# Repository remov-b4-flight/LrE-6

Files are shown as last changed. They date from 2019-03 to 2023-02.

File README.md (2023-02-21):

Current development was moved to 8-Axis [LrTMAX](https://github.com/remov-b4-flight/LrTMAX) repository.
***
# LrE-6
Adobe Lightroom MIDI Developer Controller project (STM32F072Cx based)  
LrE-6 MIDI controller is formed by embedded hardware board and its firmware.  
It used with [MIDI2LR](https://github.com/rsjaffe/MIDI2LR) software,  
You can control development parameters on RAW photos.  
[YouTube](https://www.youtube.com/watch?v=oeDpP1sG9_Y)  
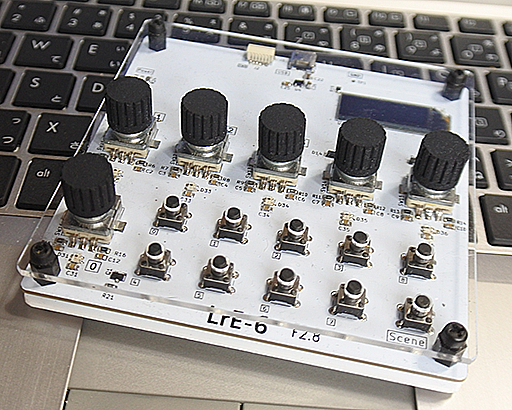
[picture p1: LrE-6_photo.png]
  
Information related Build,Configure & Use are exists on wiki.  
***
Lightroom is Registerd Trademark of Adobe Corp.

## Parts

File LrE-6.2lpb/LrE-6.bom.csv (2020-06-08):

Reference | Quantity | Value | Footprint | Datasheet
C1 C2 C3 C4 C7 C8 C9 C10 C11 C12 C5 C6 C25 | 13 | 0.01u | Capacitor_SMD:C_0805_2012Metric | ~
C13 C16 C17 C18 C14 | 5 | 0.1u | Capacitor_SMD:C_0603_1608Metric | ~
C15 C19 C28 C29 | 4 | 4.7u | Capacitor_SMD:C_0805_2012Metric | ~
C26 C22 C23 C24 C21 C20 C27 | 7 | 1u | Capacitor_SMD:C_0805_2012Metric | ~
C31 C32 C33 C35 C36 C34 C30 | 7 | 0.1u | Capacitor_SMD:C_0805_2012Metric | ~
D18 | 1 | LED0603_BL | LED_SMD:LED_0603_1608Metric | ~
D31 D32 D33 D34 D35 D36 | 6 | WS2812B-2020 | LrE-6:LED_WS2812B-2020 | https://cdn-shop.adafruit.com/product-files/2686/SK6812MINI_REV.01-1-2.pdf
D4 D9 D3 D8 D2 D7 D10 D1 D6 D5 D12 D11 D13 D14 D15 D16 | 16 | 1N4148W | LrE-6:D_SOD-123 | https://www.vishay.com/docs/85748/1n4148w.pdf
H1 H2 H3 H4 | 4 | MountingHole | MountingHole:MountingHole_3.2mm_M3 | ~
J1 | 1 | USB_B_Micro | LrE-6:USB_Micro-B_MCUBF-09_1 | ~
J2 | 1 | SM06B-SRSS-TB | Connector_JST:JST_SH_SM06B-SRSS-TB_1x06-1MP_P1.00mm_Horizontal | ~
Q1 | 1 | 2N7002 | Package_TO_SOT_SMD:SOT-23 | https://www.fairchildsemi.com/datasheets/2N/2N7002.pdf
R18 | 1 | 62 | Resistor_SMD:R_0805_2012Metric | ~
R19 R20 R6 R5 R8 R7 R10 R9 R12 R11 R14 R13 R16 R15 R17 R21 | 16 | 10K | Resistor_SMD:R_0805_2012Metric | ~
R23 | 1 | 100 | Resistor_SMD:R_0805_2012Metric | ~
R4 R3 R2 R1 R24 R22 | 6 | 1K | Resistor_SMD:R_0805_2012Metric | ~
SW1 SW2 SW3 SW4 SW5 SW6 SW7 SW8 SW9 SW10 | 10 | Tact_SW_8mm | Button_Switch_THT:SW_PUSH_6mm_H9.5mm
SW11 SW12 SW13 SW14 SW15 SW16 | 6 | EC11_SMD | LrE-6:RotaryEncoder_EC11E-SMD2 | ~
TP1 | 1 | TestPoint | TestPoint:TestPoint_THTPad_D1.0mm_Drill0.5mm | ~
U1 | 1 | STM32F072C8Tx | Package_QFP:LQFP-48_7x7mm_P0.5mm | http://www.st.com/st-web-ui/static/active/en/resource/technical/document/datasheet/DM00090510.pdf
U3 | 1 | SSD1306_OLED_0.91 | LrE-6:OLED-9.1
U4 | 1 | SPX3819M5-L3-3TR | Package_TO_SOT_SMD:SOT-23-5 | http://www.st.com/content/ccc/resource/technical/document/datasheet/29/10/f7/87/2f/66/47/f4/DM00076097.pdf/files/DM00076097.pdf/jcr:content/translations/en.DM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

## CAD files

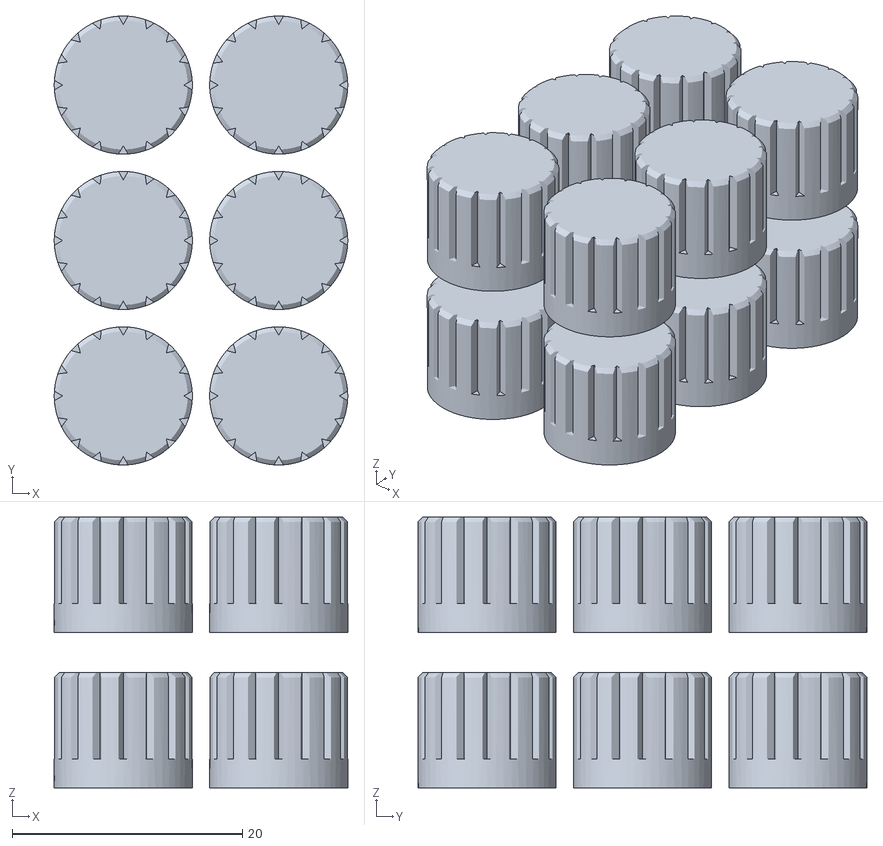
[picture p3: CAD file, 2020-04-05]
LrE-6.knob/knob12-hollow.stl
25.5 x 39.0 x 23.5

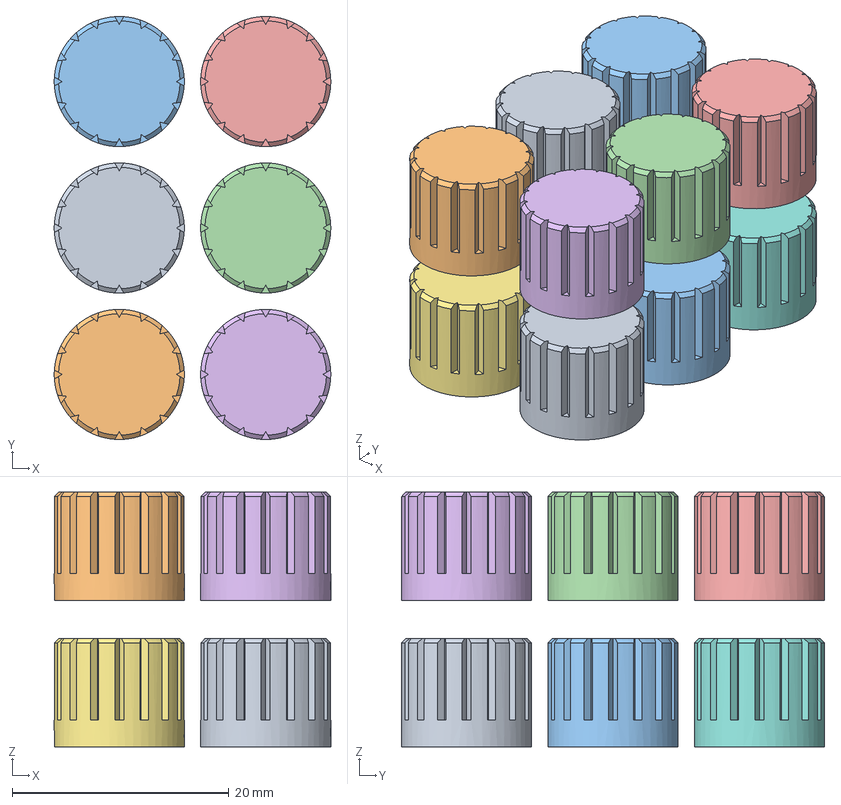
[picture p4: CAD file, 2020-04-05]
LrE-6.knob/KNOB12.FCStd
25.5 x 39.0 x 23.5 mm

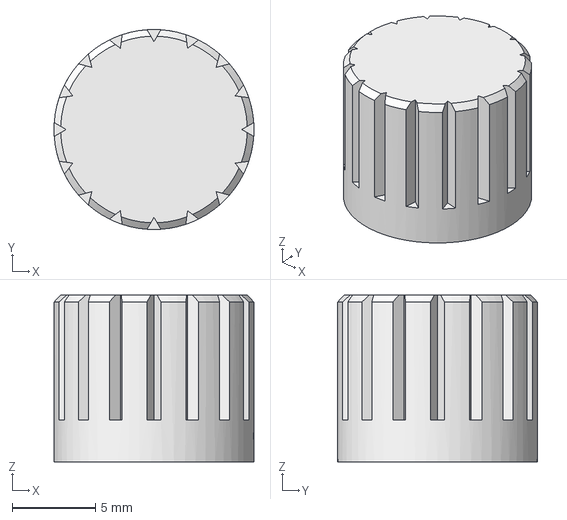
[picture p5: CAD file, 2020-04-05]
LrE-6.knob/KNOB1.FCStd
12.0 x 12.0 x 10.0 mm

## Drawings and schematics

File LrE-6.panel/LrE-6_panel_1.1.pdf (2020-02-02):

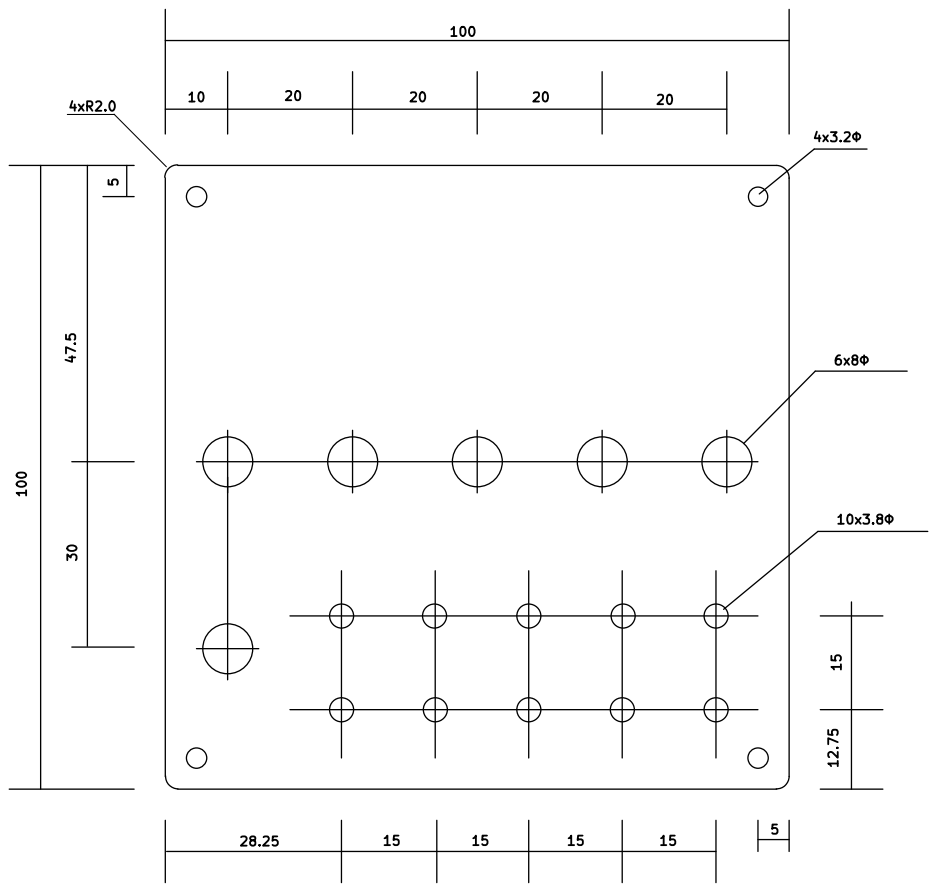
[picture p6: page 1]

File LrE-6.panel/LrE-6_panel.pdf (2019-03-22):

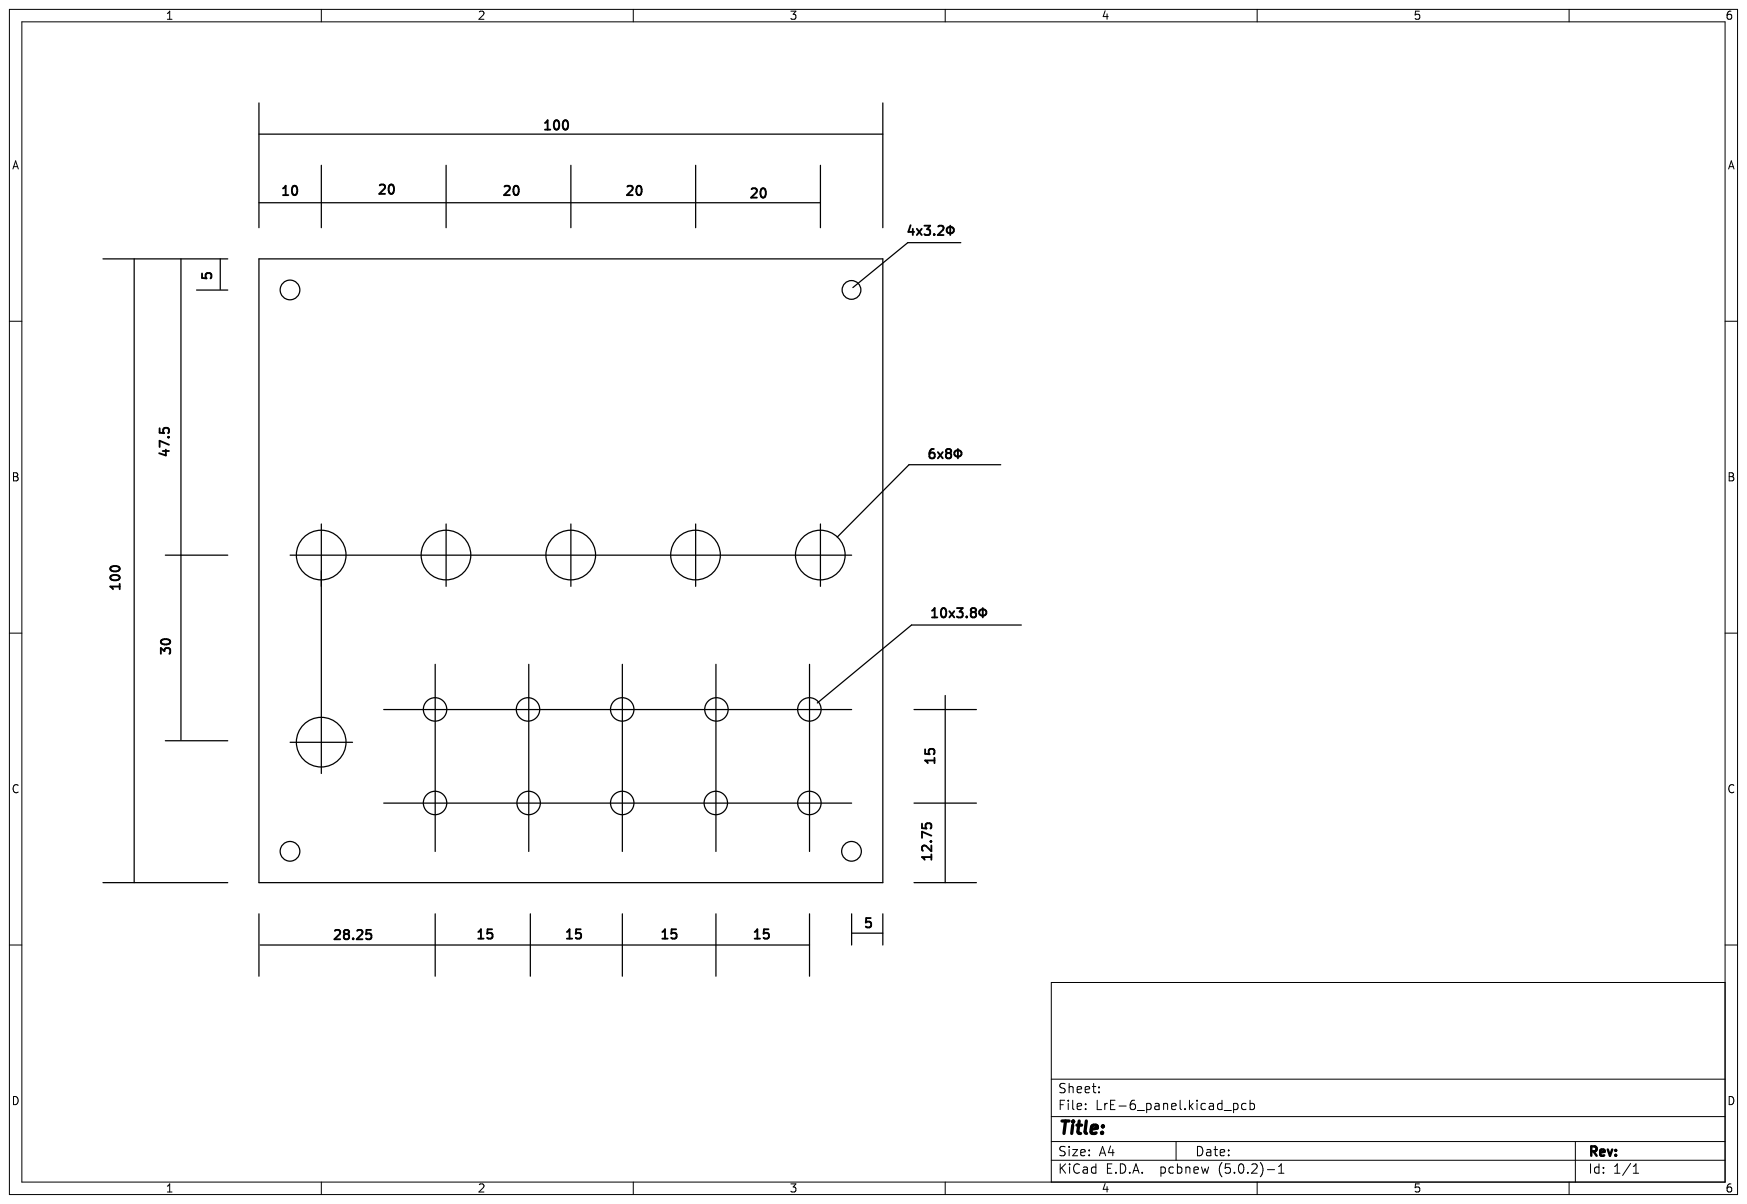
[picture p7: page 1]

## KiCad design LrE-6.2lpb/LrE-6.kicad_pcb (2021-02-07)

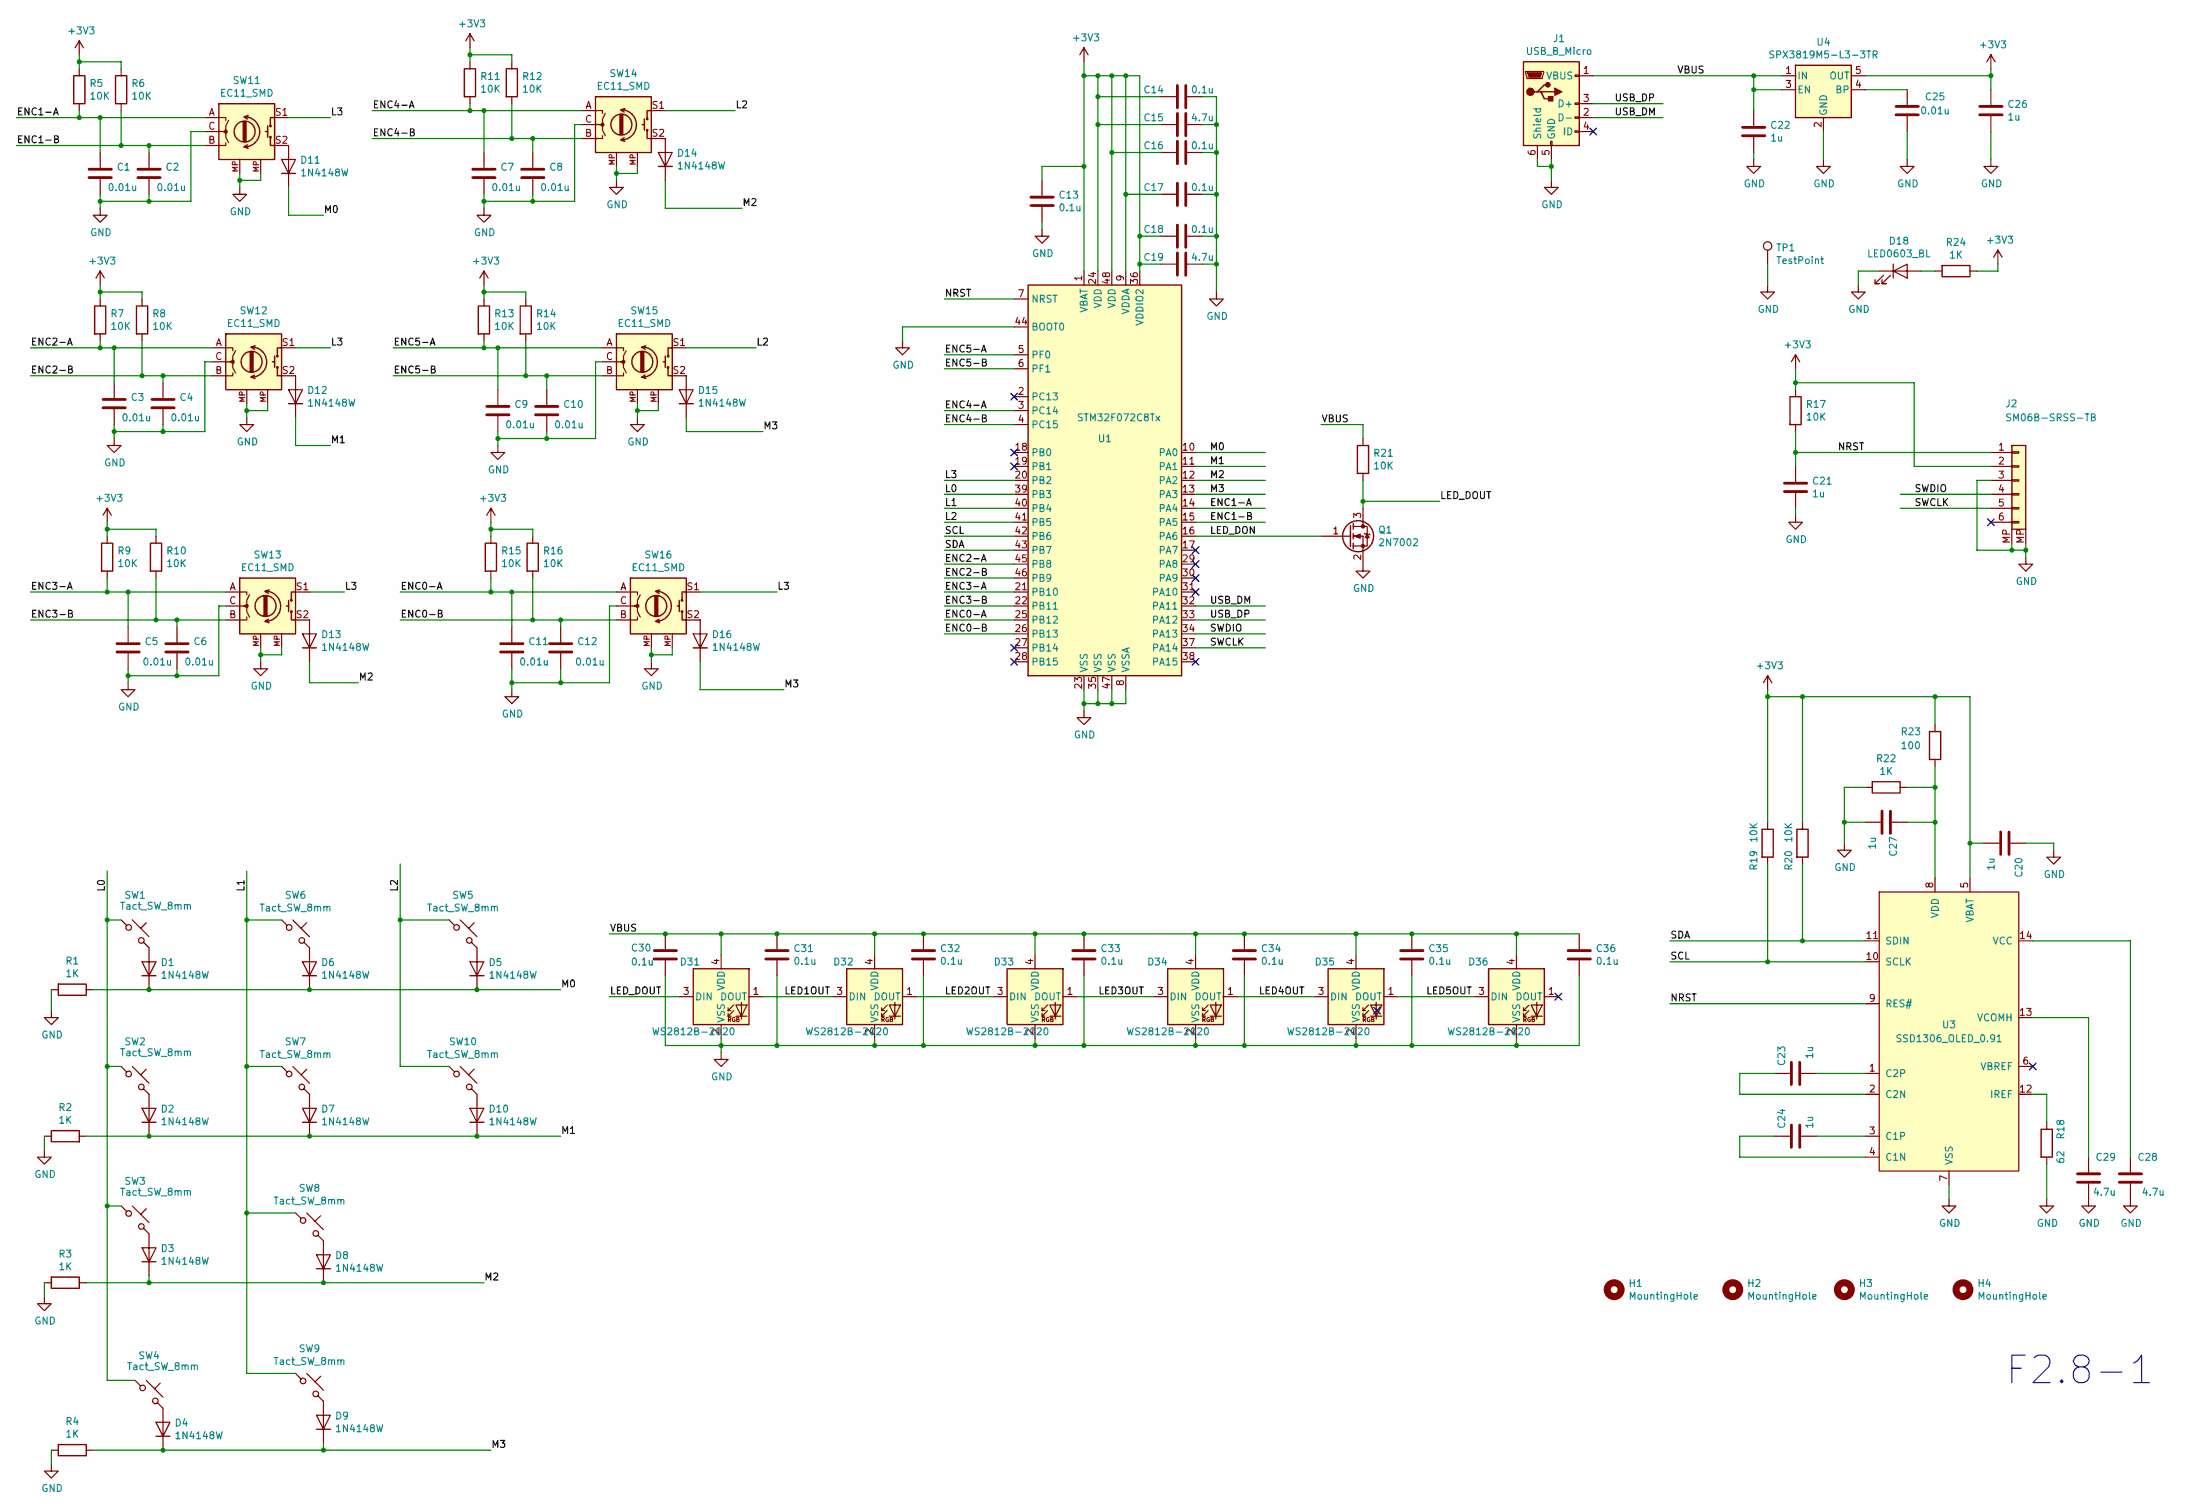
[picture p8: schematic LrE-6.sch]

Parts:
C1, C2, C3, C4, C5, C6, C7, C8, C9, C10, C11, C12, C25: 0.01u; C_0805_2012Metric
C13, C14, C16, C17, C18: 0.1u; C_0603_1608Metric
C15, C19, C28, C29: 4.7u; C_0805_2012Metric
C20, C21, C22, C23, C24, C26, C27: 1u; C_0805_2012Metric
C30, C31, C32, C33, C34, C35, C36: 0.1u; C_0805_2012Metric
D1, D2, D3, D4, D5, D6, D7, D8, D9, D10, D11, D12, D13, D14, D15, D16: 1N4148W; D_SOD-123
D18: LED0603_BL; LED_0603_1608Metric
D31, D32, D33, D34, D35, D36: WS2812B-2020; LED_WS2812B-2020
H1, H2, H3, H4: MountingHole; MountingHole_3.2mm_M3
J1: USB_B_Micro; USB_Micro-B_MCUBF-09_1
J2: SM06B-SRSS-TB; JST_SH_SM06B-SRSS-TB_1x06-1MP_P1.00mm_Horizontal
Q1: 2N7002; SOT-23
R1, R2, R3, R4, R22, R24: 1K; R_0805_2012Metric
R5, R6, R7, R8, R9, R10, R11, R12, R13, R14, R15, R16, R17, R19, R20, R21: 10K; R_0805_2012Metric
R18: 62; R_0805_2012Metric
R23: 100; R_0805_2012Metric
SW1, SW2, SW3, SW4, SW5, SW6, SW7, SW8, SW9, SW10: Tact_SW_8mm; SW_PUSH_6mm_H9.5mm
SW11, SW12, SW13, SW14, SW15, SW16: EC11_SMD; RotaryEncoder_Alps_EC11E-Switch_Vertical_H20mm
TP1: TestPoint; TestPoint_THTPad_D1.0mm_Drill0.5mm
U1: STM32F072C8Tx; LQFP-48_7x7mm_P0.5mm
U3: SSD1306_OLED_0.91; OLED-9.1
U4: SPX3819M5-L3-3TR; SOT-23-5

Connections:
+3V3: C13.1, C14.2, C15.2, C16.2, C17.2, C18.2, C19.2, C20.1, C26.1, J2.2, R5.1, R6.1, R7.1, R8.1, R9.1, R10.1, R11.1, R12.1, R13.1, R14.1, R15.1, R16.1, R17.1, R19.1, R20.1, R23.1, R24.1, U1.1 (VBAT), U1.9 (VDDA), U1.24 (VDD), U1.36 (VDDIO2), U1.48 (VDD), U3.5 (VBAT), U4.5 (OUT)
/ENC0-A: C11.1, R15.2, SW16.A, U1.25 (PB12)
/ENC0-B: C12.1, R16.2, SW16.B, U1.26 (PB13)
/ENC1-A: C1.1, R5.2, SW11.A, U1.14 (PA4)
/ENC1-B: C2.1, R6.2, SW11.B, U1.15 (PA5)
/ENC2-A: C3.1, R7.2, SW12.A, U1.45 (PB8)
/ENC2-B: C4.1, R8.2, SW12.B, U1.46 (PB9)
/ENC3-A: C5.1, R9.2, SW13.A, U1.21 (PB10)
/ENC3-B: C6.1, R10.2, SW13.B, U1.22 (PB11)
/ENC4-A: C7.1, R11.2, SW14.A, U1.3 (PC14)
/ENC4-B: C8.1, R12.2, SW14.B, U1.4 (PC15)
/ENC5-A: C9.1, R13.2, SW15.A, U1.5 (PF0)
/ENC5-B: C10.1, R14.2, SW15.B, U1.6 (PF1)
/L0: SW1.1, SW2.1, SW3.1, SW4.1, U1.39 (PB3)
/L1: SW6.1, SW7.1, SW8.1, SW9.1, U1.40 (PB4)
/L2: SW5.1, SW10.1, SW14.S1, SW15.S1, U1.41 (PB5)
/L3: SW11.S1, SW12.S1, SW13.S1, SW16.S1, U1.20 (PB2)
/LED1OUT: D31.1 (DOUT), D32.3 (DIN)
/LED2OUT: D32.1 (DOUT), D33.3 (DIN)
/LED3OUT: D33.1 (DOUT), D34.3 (DIN)
/LED4OUT: D34.1 (DOUT), D35.3 (DIN)
/LED5OUT: D35.1 (DOUT), D36.3 (DIN)
/LED_DON: Q1.1 (G), U1.16 (PA6)
/LED_DOUT: D31.3 (DIN), Q1.3 (D), R21.2
/M0: D1.1 (K), D5.1 (K), D6.1 (K), D11.1 (K), R1.1, U1.10 (PA0)
/M1: D2.1 (K), D7.1 (K), D10.1 (K), D12.1 (K), R2.2, U1.11 (PA1)
/M2: D3.1 (K), D8.1 (K), D13.1 (K), D14.1 (K), R3.1, U1.12 (PA2)
/M3: D4.1 (K), D9.1 (K), D15.1 (K), D16.1 (K), R4.1, U1.13 (PA3)
/NRST: C21.1, J2.1, R17.2, U1.7 (NRST), U3.9 (RES#)
/SCL: R19.2, U1.42 (PB6), U3.10 (SCLK)
/SDA: R20.2, U1.43 (PB7), U3.11 (SDIN)
/SWCLK: J2.5, U1.37 (PA14)
/SWDIO: J2.4, U1.34 (PA13)
/USB_DM: J1.2 (D-), U1.32 (PA11)
/USB_DP: J1.3 (D+), U1.33 (PA12)
/VBUS: C22.1, C30.1, C31.1, C32.1, C33.1, C34.1, C35.1, C36.1, D31.4 (VDD), D32.4 (VDD), D33.4 (VDD), D34.4 (VDD), D35.4 (VDD), D36.4 (VDD), J1.1 (VBUS), R21.1, U4.1 (IN), U4.3 (EN)
GND: C1.2, C2.2, C3.2, C4.2, C5.2, C6.2, C7.2, C8.2, C9.2, C10.2, C11.2, C12.2, C13.2, C14.1, C15.1, C16.1, C17.1, C18.1, C19.1, C20.2, C21.2, C22.2, C25.2, C26.2, C27.1, C28.1, C29.1, C30.2, C31.2, C32.2, C33.2, C34.2, C35.2, C36.2, D18.1 (K), D31.2 (VSS), D32.2 (VSS), D33.2 (VSS), D34.2 (VSS), D35.2 (VSS), D36.2 (VSS), J1.5 (GND), J1.6 (Shield), J2.3, J2.MP (GND), Q1.2 (S), R1.2, R2.1, R3.2, R4.2, R18.2, R22.2, SW11.C, SW11.MP (GND), SW12.C, SW12.MP (GND), SW13.C, SW13.MP (GND), SW14.C, SW14.MP (GND), SW15.C, SW15.MP (GND), SW16.C, SW16.MP (GND), TP1.1, U1.8 (VSSA), U1.23 (VSS), U1.35 (VSS), U1.44 (BOOT0), U1.47 (VSS), U3.7 (VSS), U4.2 (GND)
unnamed: C23.1, U3.2 (C2N)
unnamed: C23.2, U3.1 (C2P)
unnamed: C24.1, U3.4 (C1N)
unnamed: C24.2, U3.3 (C1P)
unnamed: C25.1, U4.4 (BP)
unnamed: C27.2, R22.1, R23.2, U3.8 (VDD)
unnamed: C28.2, U3.14 (VCC)
unnamed: C29.2, U3.13 (VCOMH)
unnamed: D1.2 (A), SW1.2
unnamed: D2.2 (A), SW2.2
unnamed: D3.2 (A), SW3.2
unnamed: D4.2 (A), SW4.2
unnamed: D5.2 (A), SW5.2
unnamed: D6.2 (A), SW6.2
unnamed: D7.2 (A), SW7.2
unnamed: D8.2 (A), SW8.2
unnamed: D9.2 (A), SW9.2
unnamed: D10.2 (A), SW10.2
unnamed: D11.2 (A), SW11.S2
unnamed: D12.2 (A), SW12.S2
unnamed: D13.2 (A), SW13.S2
unnamed: D14.2 (A), SW14.S2
unnamed: D15.2 (A), SW15.S2
unnamed: D16.2 (A), SW16.S2
unnamed: D18.2 (A), R24.2
unnamed: R18.1, U3.12 (IREF)

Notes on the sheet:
F2.8-1

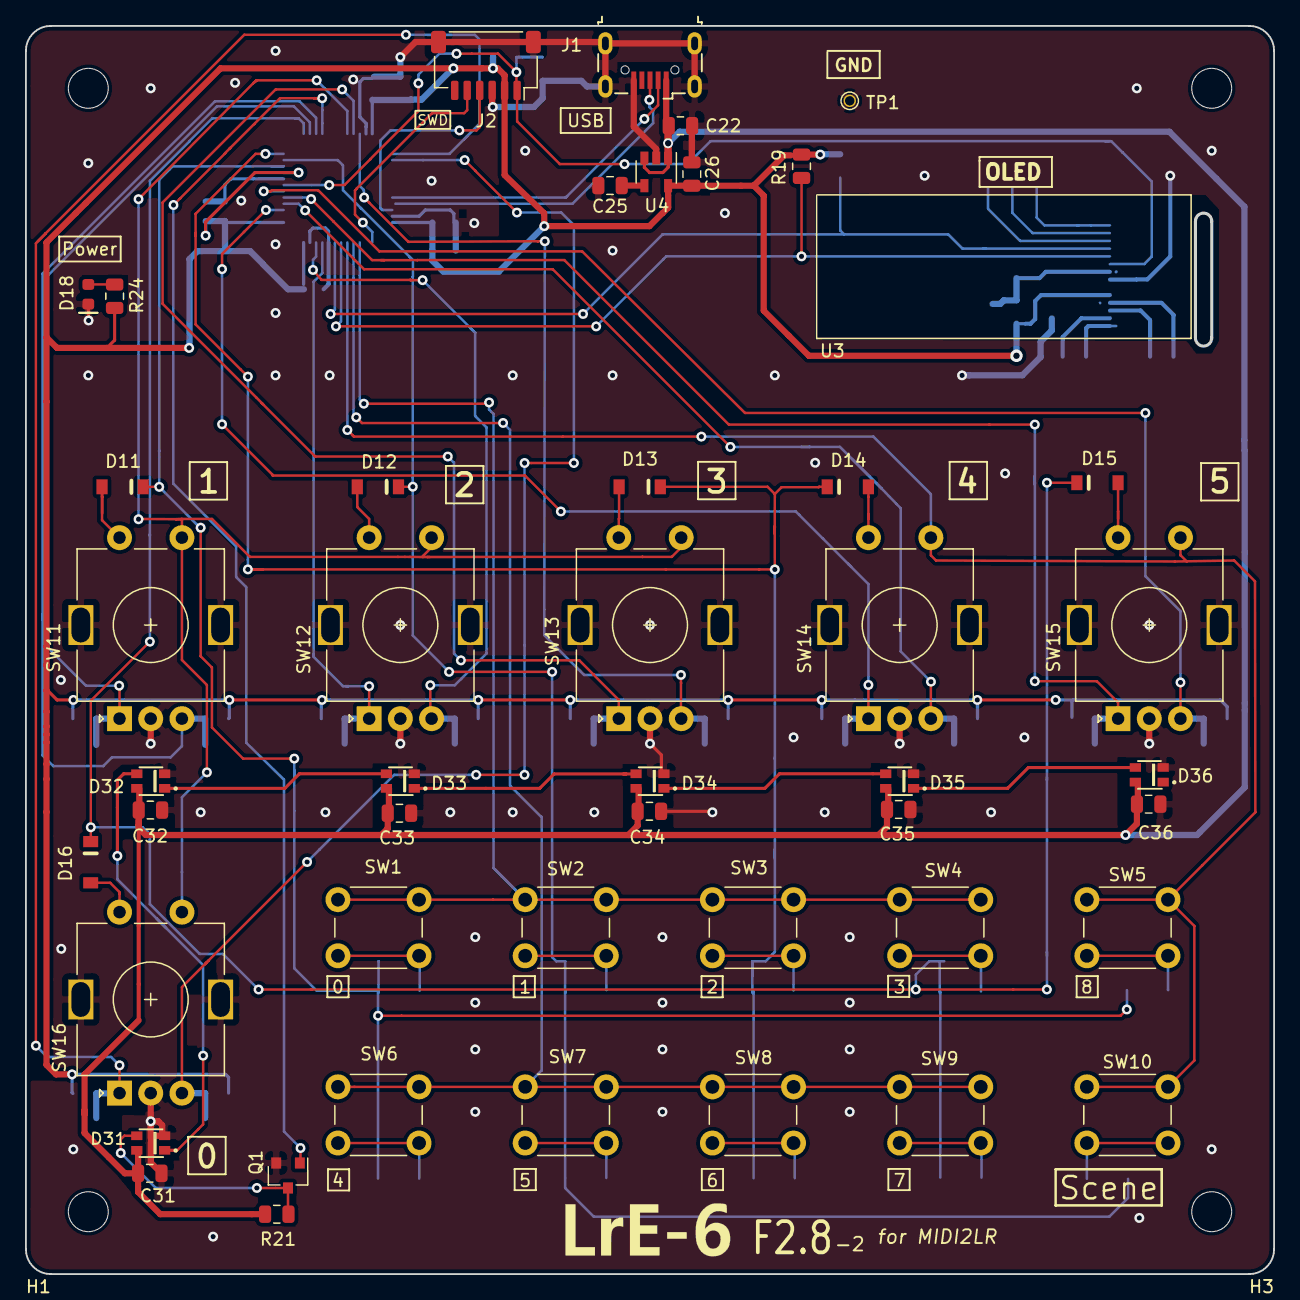
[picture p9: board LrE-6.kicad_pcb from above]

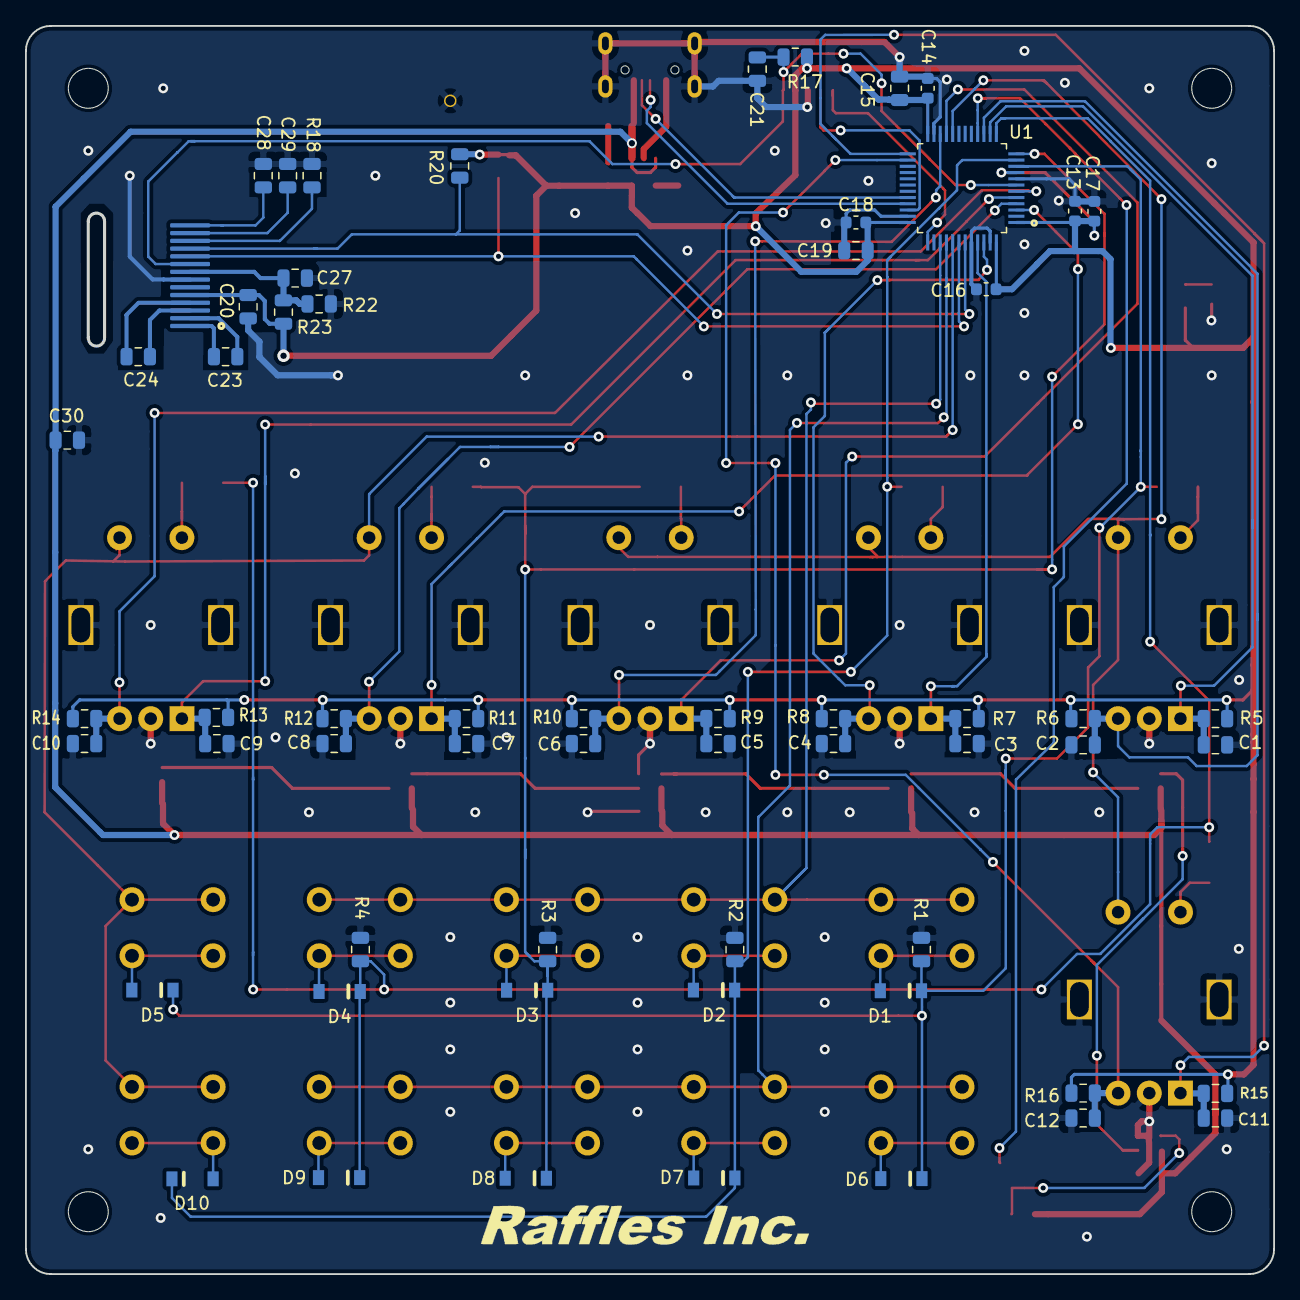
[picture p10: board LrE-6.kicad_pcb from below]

Board: 2 copper layers, 100.0 x 100.0 mm, 112 parts (60 on the bottom side), 63 nets.

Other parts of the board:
G001: LrE-6; LOGO
G002: LOGO; Raffles_Inc

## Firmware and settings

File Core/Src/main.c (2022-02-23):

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
/* Includes ------------------------------------------------------------------*/
#include "main.h"
#include "usb_device.h"

/* USER CODE BEGIN Includes */
#include <stdbool.h>
#include "midi.h"
#include "led.h"
#include "bitcount.h"
#include "key_define.h"
#include "usbd_midi_if.h"
#include "ssd1306.h"
/* USER CODE END Includes */

/* USER CODE BEGIN PTD */
#ifdef DEBUG
#define CONN_MSG_D	"%s %2x.%02xD"
#else
#define CONN_MSG	"%s %2x.%02x"
#endif
/* USER CODE END PTD */

I2C_HandleTypeDef hi2c1;
DMA_HandleTypeDef hdma_i2c1_tx;

TIM_HandleTypeDef htim1;
TIM_HandleTypeDef htim3;
TIM_HandleTypeDef htim6;
TIM_HandleTypeDef htim7;
TIM_HandleTypeDef htim14;
DMA_HandleTypeDef hdma_tim3_ch1_trig;

/* USER CODE BEGIN PV */

//! STM32 TIM3 instance handle
TIM_HandleTypeDef htim3;
extern	USBD_HandleTypeDef hUsbDeviceFS;
//! Lr**** USB connection state
uint8_t		LrState;
//! Lr**** Scene index
uint8_t		LrScene;
// keyboard variable
//! If true, ISR detected any Key/Encoder was moved.
bool		isKeyPressed;
//! Key pressed/released status set by timer key scanning.
KEYSCAN     Key_Stat;
//! In key scanning whether Line selected to read for key matrix.
uint8_t		Key_Line;
//! If true, MIDI event previous sent is switch. if false, it's encoder
bool		isPrev_sw;
//! Bit masks for which bit of KEYSCAN variable acts as key.
uint32_t	MaskKey[SCENE_COUNT];
//! Bit masks for which bit of KEYSCAN variable acts as encoder.
uint32_t	MaskEnc[SCENE_COUNT];

// OLED variables
//! Flag set by timer ISR, It makes 'off' OLES contents.
bool 		Msg_Timer_Update;
//! Timer counter ticked by end of L3 matrix scanning. (16ms interval).
int32_t		Msg_Timer_Count;
//! If true Msg_Timer counting is enabled.
bool		Msg_Timer_Enable;
//! If true, Screen is cleared in main() that is determined on timer interrupt.
bool		Msg_Off_Flag;
//! If true, Screen is flashed by Msg_Buffer[] at main() function.
static	bool	isMsgFlash;
//! If true, frame_buffer[] contents flashes the screen.
static	bool	isRender;

// LED variables
//! If true, LEDs are flashed by LEDColor[] array.
bool		isLEDsendpulse;
//! Flag is set by timer ISR, It makes LED_Timer[] count up in main()
bool		LED_Timer_Update;

// Scene related
extern	KEY_DEFINE keytable[SCENE_COUNT][DEFINES_PER_SCENE];
extern	char *scene_name[SCENE_COUNT];
extern	uint8_t	led_axis_table[DEFINES_PER_SCENE];

extern	uint8_t	LED_Scene[SCENE_COUNT][LED_COUNT];
extern	uint8_t	LEDColor[LED_COUNT];
extern	uint8_t	LEDTimer[LED_COUNT];

//! String message buffer of screen
extern char Msg_Buffer[MSG_LINES][MSG_WIDTH + 1];

// MIDI variables
//! MIDI CC message value for each channels.
uint8_t MIDI_CC_Value[SCENE_COUNT][ENC_COUNT];
//! keep previous sent 'Key On' note/channel for release message.
uint8_t prev_note;
//! USB MIDI message structure for send
MIDI_EVENT	USBMIDI_Event;

//! Instance Handle of USB interface
extern USBD_HandleTypeDef *pInstance;

/* USER CODE END PV */

void SystemClock_Config(void);
static void MX_GPIO_Init(void);
static void MX_DMA_Init(void);
static void MX_I2C1_Init(void);
static void MX_TIM3_Init(void);
static void MX_TIM1_Init(void);
static void MX_TIM14_Init(void);
static void MX_TIM6_Init(void);
static void MX_TIM7_Init(void);
/* USER CODE BEGIN PFP */
void EmulateKeyboard();
/* USER CODE END PFP */

/* USER CODE BEGIN 0 */

/**
 *	@brief	Mask all EXTI lines of encoders
 */
static void Stop_All_Encoders(){
	uint32_t temp = EXTI->IMR;
	temp &= 0xffff0000;
	EXTI->IMR = temp;
}
/**
 * @brief	Release all EXTI lines masked by StopAllEncoders()
 */
static void Start_All_Encoders(){
	uint32_t temp = EXTI->IMR;
	temp |= 0x0000ffff;
	EXTI->IMR = temp;
}

static inline void Start_MsgTimer(uint32_t tick){
	Msg_Off_Flag = false;
	Msg_Timer_Count = tick;
	Msg_Timer_Enable = true;
}

static inline void Msg_Print(){
	isMsgFlash = true;
}

/**
 * @brief alter LED contents by scene
 * @param scene	Scene No
 */
static void LED_SetScene(uint8_t scene){
	memcpy(LEDColor, LED_Scene[scene], LED_COUNT);
	LED_SendPulse();
}
/**
 * @brief Make MaskKey[],MaskRot[] from keytable[](in key_define.c)
 * @return false : there is some configuration error.
 */
static void	MakeMasks(){
	for(uint8_t scn = 0; scn < SCENE_COUNT; scn++){
		for(uint8_t bit = 0; bit < DEFINES_PER_SCENE; bit++){
			uint32_t	or_bit = (1 << bit);
			MaskKey[scn] |= (keytable[scn][bit].type == TYPE_SWITCH)?	or_bit : 0;
			MaskEnc[scn] |= (keytable[scn][bit].type == TYPE_ROTARY)?	or_bit : 0;
		}
	}
}

/**
 *	@brief	Generate MIDI event and Send to host by User interaction.
 *	@return true : function processed any Key/Encoder event.
 *	@pre	isKeyPressed	any key is pressed or not
 *	@pre	Key_Stat		current key status
 */
static void EmulateMIDI(){
	char msg_string[MSG_WIDTH];

	if (isKeyPressed) {
    	//Send 'Note On' Event from key matrix
        uint8_t		bitpos = ntz32(Key_Stat.wd);
        uint32_t	rkey = (Key_Stat.wd);
        bool 		isKeyReport = false;

        if ( Key_Stat.wd & MaskKey[LrScene] ) { //Matrix switches
        	uint8_t	note = (LrScene * NOTES_PER_SCENE) + bitpos;
        	if (bitpos == SCENE_BIT) { //is [SCENE] switch pressed?
            	//Move to next Scene.
            	if((++LrScene) >= SCENE_COUNT){
            		LrScene = Lr_SCENE0;
        		}
        		LED_SetScene(LrScene);
        		strcpy(msg_string, scene_name[LrScene]);
        	}else{
                LED_SetPulse(keytable[LrScene][bitpos].axis, keytable[LrScene][bitpos].color, keytable[LrScene][bitpos].period);
            	sprintf(msg_string, "Note: %3d    S%1d", note, (LrScene % SCENE_COUNT) );
        	}
                isKeyReport = true;

            //Print Message to OLED & LED
            if (keytable[LrScene][bitpos].message != NULL) {
            	SSD1306_SetScreen(ON);

        		strcpy(Msg_Buffer[0], keytable[LrScene][bitpos].message);
        		strcpy(Msg_Buffer[1], msg_string);
        		Msg_Print();

            	Start_MsgTimer(MSG_TIMER_DEFAULT);
            }

            if (isKeyReport == true) {
				//Set 'Note ON
				USBMIDI_Event.header = MIDI_NT_ON;
				USBMIDI_Event.status = MIDI_NT_ON_S;
				USBMIDI_Event.channel = note;
				USBMIDI_Event.value = MIDI_NT_VELOCITY;

				prev_note = note;
				isPrev_sw = true;
            }
        }else if( Key_Stat.wd & MaskEnc[LrScene] ) {
        	//Send CC Event from encoder
        	uint8_t axis = (bitpos - KEY_COUNT) / 2;
        	uint8_t val = MIDI_CC_Value[LrScene][axis];
        	uint8_t channel = CC_CH_OFFSET + (LrScene * CC_CH_PER_SCENE) + axis;

            USBMIDI_Event.header = MIDI_CC_HEADER;
            USBMIDI_Event.status = MIDI_CC_STATUS;
            USBMIDI_Event.channel = channel;
            USBMIDI_Event.value = val;

            isPrev_sw = false;

            //Print Message to OLED & LED
            if (keytable[LrScene][bitpos].message != NULL) {
            	SSD1306_SetScreen(ON);
                sprintf(msg_string,
                	((channel > 99)? "C%3d = %3d    S%1d" : "Ch%1d = %3d    S%1d"), channel, val, LrScene);
                strcpy(Msg_Buffer[0], keytable[LrScene][bitpos].message);
            	strcpy(Msg_Buffer[1], msg_string);
            	Msg_Print();

            	Start_MsgTimer(MSG_TIMER_DEFAULT);
            }
            LED_SetPulse(keytable[LrScene][bitpos].axis, keytable[LrScene][bitpos].color, keytable[LrScene][bitpos].period);
            isKeyReport = true;

        }else if(isPrev_sw == true && rkey == 0) {// Switch is released
			//Send 'Note Off' Event
			USBMIDI_Event.header = MIDI_NT_OFF;
			USBMIDI_Event.status = MIDI_NT_OFF_S;
			USBMIDI_Event.channel = prev_note;
			USBMIDI_Event.value = MIDI_NT_VELOCITY;

			isKeyReport = true;
			isPrev_sw = false;
        }

        if(isKeyReport == true){
			//Send MIDI event via USB
		    USBD_LL_Transmit (pInstance, MIDI_IN_EP, (uint8_t *)&USBMIDI_Event, MIDI_EVENT_LENGTH);
			isKeyReport = false;
        }

        /* Clear the switch pressed flag */
        isKeyPressed = false;
    }
}
/* USER CODE END 0 */

/**
  * @brief  The application entry point.
  * @retval int
  */
int main(void)
{
  /* USER CODE BEGIN 1 */
  //! Indicates 1st Msg_Timer timeout has occurred from power on reset.
  bool Msg_1st_timeout = true;
  /* USER CODE END 1 */

  /* MCU Configuration--------------------------------------------------------*/

  /* Reset of all peripherals, Initializes the Flash interface and the Systick. */
  HAL_Init();

  /* USER CODE BEGIN Init */
  Key_Line = L0;
  Msg_Off_Flag = false;
  Msg_Timer_Enable = false;
  Msg_Timer_Count = MSG_TIMER_DEFAULT;
  isMsgFlash = false;
  isRender = true;

  LrState = LR_RESET;
  LrScene = Lr_SCENE0;

  isPrev_sw = false;
  isLEDsendpulse = false;
  Msg_Timer_Update = false;
  LED_Timer_Update = false;
  /* USER CODE END Init */

  /* Configure the system clock */
  SystemClock_Config();

  /* Initialize all configured peripherals */
  MX_GPIO_Init();
  MX_DMA_Init();
  MX_I2C1_Init();
  MX_TIM3_Init();
  MX_TIM1_Init();
  MX_TIM14_Init();
#if 1
  MX_USB_MIDI_INIT();
#else
  MX_USB_DEVICE_Init();
#endif
  MX_TIM7_Init();
  MX_TIM6_Init();
  /* USER CODE BEGIN 2 */
  //Stop All Encoders until USB link up
  Stop_All_Encoders();
  //Initialize Switch matrix
  HAL_GPIO_WritePin(L0_GPIO_Port, L0_Pin, GPIO_PIN_SET);	//Initialize L0-3.
  MakeMasks();

  //Initialize series of WS2812C
  GPIOA->PUPDR |= GPIO_PUPDR_PUPDR6_0;	//Pull up PA6 (WS2812C-2020 workaround)
  GPIOA->ODR |= GPIO_PIN_6;				//'RESET' state
  //AF -> GPIO
  GPIOA->MODER &= ~(GPIO_MODER_MODER6_1);
  GPIOA->MODER |=	GPIO_MODER_MODER6_0;

  LED_Initialize();						//Set all LEDs to 'OFF'

  //Initialize SSD1306 OLED
  HAL_Delay(SSD1306_PWRUP_WAIT);		//Wait for OLED module power up.
  SSD1306_Initialize();
  /* USER CODE END 2 */

  /* Infinite loop */
  /* USER CODE BEGIN WHILE */
  uint32_t	nc_count = 0;

  HAL_TIM_Base_Start_IT(&htim6);		//Start LED timer.
  HAL_TIM_Base_Start_IT(&htim7);		//Start Message timer.
  Start_MsgTimer(MSG_TIMER_DEFAULT);
  LrState = LR_USB_NOLINK;

  //Initialize CC Value table
  memset(MIDI_CC_Value, MIDI_CC_INITIAL, SCENE_COUNT * ENC_COUNT);

  //LED Initialize
  LED_SetScene(LrScene);

  //Main loop
  while (1) {
	if (LrState == LR_USB_LINKUP) {
		//USB device configured by host
		SSD1306_SetScreen(ON);
		HAL_TIM_Base_Start_IT(&htim1);		//Start Switch matrix timer.
		Start_All_Encoders();				//Start rotary encoder.

#ifdef DEBUG
		int ch = ' ';
		sprintf(Msg_Buffer[0], CONN_MSG_D, Lr_PRODUCT, USBD_DEVICE_VER_MAJ, USBD_DEVICE_VER_MIN);
		memset(Msg_Buffer[1], ch, MSG_WIDTH );
		Msg_Print();
#else
		SSD1306_LoadBitmap();
		sprintf(Msg_Buffer[0], CONN_MSG, Lr_PRODUCT, USBD_DEVICE_VER_MAJ, USBD_DEVICE_VER_MIN);
		SSD1306_RenderBanner(Msg_Buffer[0], 12, 12);
		SSD1306_FlashScreen();
#endif
		Start_MsgTimer(MSG_TIMER_DEFAULT);
		memcpy(LEDColor,LED_Scene[LrScene],LED_COUNT);
		LED_SetPulse(LED_IDX_ENC0, LED_PINK, LED_TIM_CONNECT);
		LrState = LR_USB_LINKED;

	} else if (LrState == LR_USB_LINKED) {
		//Operate as MIDI Instruments.
		EmulateMIDI();
	} else if(LrState == LR_USB_LINK_LOST) {
		LrScene	= Lr_SCENE0;
		Stop_All_Encoders();
		HAL_TIM_Base_Stop(&htim1);

		LED_TestPattern();
		Msg_1st_timeout = false;
		Start_MsgTimer(MSG_TIMER_DEFAULT);
		nc_count = 0;
		LrState = LR_USB_NOLINK;

	} else if(LrState == LR_USB_NOLINK) {
		//USB can't be configured or disconnected by host.
		if (Msg_Off_Flag == true) {
			if (Msg_1st_timeout == true) {
				LrState = LR_USB_LINK_LOST;
			} else { // 2nd or more
				sprintf(Msg_Buffer[0], "%12ld", nc_count++);
				SSD1306_SetScreen(ON);

				Msg_Print();

				//Restart OLED timer.
				Start_MsgTimer(MSG_TIMER_UPDATE);

				//Rotate LED colors
				uint8_t	tempcolor = LEDColor[5];
				LEDColor[5] = LEDColor[4];
				LEDColor[4] = LEDColor[3];
				LEDColor[3] = LEDColor[2];
				LEDColor[2] = LEDColor[1];
				LEDColor[1] = LEDColor[0];
				LEDColor[0] = tempcolor;

				isLEDsendpulse = true;
			}
		}// Msg_Off_Flag
	}// LrState

	//LED Timer
	if (LED_Timer_Update == true){ //24ms interval
		for (uint8_t i = 0; i < LED_COUNT; i++){
			if (LEDTimer[i] != LED_TIMER_CONSTANT && --LEDTimer[i] == 0) {
				LED_SetPulse(i, LED_Scene[LrScene][i], LED_TIMER_CONSTANT);
		 	}
		}
		LED_Timer_Update = false;
		continue;
	}

	//Flashing LEDs
	if (isLEDsendpulse == true) {
		if (LED_SendPulse() == true){
			isLEDsendpulse = false;
		}else{
			HAL_Delay(LED_TIM_RETRY_WAIT);	// i2c is busy, retry with interval
		}
		continue;
	}

	//OLED timer
	if (Msg_Timer_Update == true){
		if(Msg_Timer_Enable == true && (--Msg_Timer_Count) <= 0){
			Msg_Timer_Enable = false;
			Msg_Off_Flag = true;
		}
		Msg_Timer_Update = false;
		continue;
	}

	//OLED off Timer
	if(Msg_Off_Flag == true){
		Msg_Off_Flag = false;
		SSD1306_SetScreen(OFF);
		SSD1306_ClearBuffer();
		continue;
	}

	//Flashing OLED.
	if (isMsgFlash == true) {
		if (isRender == true) {
			SSD1306_Render2Buffer();
			isRender = false;
		}
		if (SSD1306_FlashScreen() == true) {
			isMsgFlash = false;	// success to flash
			isRender = true;
		} else {
			HAL_Delay(I2C_RETRY_WAIT);	// i2c is busy, retry with interval
		}
		continue;
	}
#ifndef DEBUG
	HAL_PWR_EnterSLEEPMode(PWR_LOWPOWERREGULATOR_ON, PWR_SLEEPENTRY_WFI);
#endif
    /* USER CODE END WHILE */

    /* USER CODE BEGIN 3 */
  }
  /* USER CODE END 3 */
}

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


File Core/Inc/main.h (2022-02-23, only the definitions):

#define USBD_DEVICE_VER_MAJ	0x00
#define USBD_DEVICE_VER_MIN	0x59
#define Lr_PID 0xA320
#define TIM_PERIOD_24mS 24576
#define TIM_PERIOD_8mS 7999
#define TIM_PERIOD_32mS 32768
#define TIM_PERIOD_125uS 125
#define PWM_HI 38
#define TIM_PRESC_1uS 47
#define Lr_VENDOR "Ruffles Inc."
#define PWM_LO 15
#define Lr_PRODUCT "LrE-6"
#define PWM_PERIOD 59
#define ENC4A_Pin GPIO_PIN_14
#define ENC4A_GPIO_Port GPIOC
#define ENC4A_EXTI_IRQn EXTI4_15_IRQn
#define ENC4B_Pin GPIO_PIN_15
#define ENC4B_GPIO_Port GPIOC
#define ENC4B_EXTI_IRQn EXTI4_15_IRQn
#define ENC5A_Pin GPIO_PIN_0
#define ENC5A_GPIO_Port GPIOF
#define ENC5A_EXTI_IRQn EXTI0_1_IRQn
#define ENC5B_Pin GPIO_PIN_1
#define ENC5B_GPIO_Port GPIOF
#define ENC5B_EXTI_IRQn EXTI0_1_IRQn
#define M0_Pin GPIO_PIN_0
#define M0_GPIO_Port GPIOA
#define M1_Pin GPIO_PIN_1
#define M1_GPIO_Port GPIOA
#define M2_Pin GPIO_PIN_2
#define M2_GPIO_Port GPIOA
#define M3_Pin GPIO_PIN_3
#define M3_GPIO_Port GPIOA
#define ENC1A_Pin GPIO_PIN_4
#define ENC1A_GPIO_Port GPIOA
#define ENC1A_EXTI_IRQn EXTI4_15_IRQn
#define ENC1B_Pin GPIO_PIN_5
#define ENC1B_GPIO_Port GPIOA
#define ENC1B_EXTI_IRQn EXTI4_15_IRQn
#define LED_DON_Pin GPIO_PIN_6
#define LED_DON_GPIO_Port GPIOA
#define L3_Pin GPIO_PIN_2
#define L3_GPIO_Port GPIOB
#define ENC3A_Pin GPIO_PIN_10
#define ENC3A_GPIO_Port GPIOB
#define ENC3A_EXTI_IRQn EXTI4_15_IRQn
#define ENC3B_Pin GPIO_PIN_11
#define ENC3B_GPIO_Port GPIOB
#define ENC3B_EXTI_IRQn EXTI4_15_IRQn
#define ENC0A_Pin GPIO_PIN_12
#define ENC0A_GPIO_Port GPIOB
#define ENC0A_EXTI_IRQn EXTI4_15_IRQn
#define ENC0B_Pin GPIO_PIN_13
#define ENC0B_GPIO_Port GPIOB
#define ENC0B_EXTI_IRQn EXTI4_15_IRQn
#define USB_DM_Pin GPIO_PIN_11
#define USB_DM_GPIO_Port GPIOA
#define USB_DP_Pin GPIO_PIN_12
#define USB_DP_GPIO_Port GPIOA
#define SWDIO_Pin GPIO_PIN_13
#define SWDIO_GPIO_Port GPIOA
#define SWCLK_Pin GPIO_PIN_14
#define SWCLK_GPIO_Port GPIOA
#define L0_Pin GPIO_PIN_3
#define L0_GPIO_Port GPIOB
#define L1_Pin GPIO_PIN_4
#define L1_GPIO_Port GPIOB
#define L2_Pin GPIO_PIN_5
#define L2_GPIO_Port GPIOB
#define SCL_Pin GPIO_PIN_6
#define SCL_GPIO_Port GPIOB
#define SDA_Pin GPIO_PIN_7
#define SDA_GPIO_Port GPIOB
#define ENC2A_Pin GPIO_PIN_8
#define ENC2A_GPIO_Port GPIOB
#define ENC2A_EXTI_IRQn EXTI4_15_IRQn
#define ENC2B_Pin GPIO_PIN_9
#define ENC2B_GPIO_Port GPIOB
#define ENC2B_EXTI_IRQn EXTI4_15_IRQn
#define Lr_PID 0xA320
#define Lr_PRODUCT "LrE-6"
#define Lr_VENDOR "Ruffles Inc."
#define KEY_COUNT	16
#define SCENE_BIT			9
#define CC_CH_OFFSET		64
#define CC_CH_PER_SCENE		8
#define NOTES_PER_SCENE		32
#define DEFINES_PER_SCENE	( KEY_COUNT + (ENC_COUNT * 2) )
#define MSG_TIMER_DEFAULT	122		//4Sec (1 tick=32.7ms)
#define MSG_TIMER_UPDATE	31		//1Sec (OLED update in USB not connected)
#define LED_TIM_NORM		21		//500ms (1 tick=24ms)
#define LED_TIM_HALF		11		//250ms
#define LED_TIM_LONG		42		//1Sec
#define LED_TIM_CONNECT		83		//2Sec
#define LED_TIM_RETRY_WAIT	21		//Transfer period for I2C
#define I2C_RETRY_WAIT		2		//Transfer period for TIM3 PWM

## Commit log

2019-03-22 1st commit
    [LrE-6 Debug.cfg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]
2019-04-02 revise PB to R1.11
    [LrE-6-B_Cu.gbl, LrE-6-B_Mask.gbs, LrE-6-B_SilkS.gbo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]
2019-06-12 R2.0
    Board Revision 2.0 & firmware working for board 2.0
    [LrE-6-B_Cu.gbl, LrE-6-B_Mask.gbs, LrE-6-B_SilkS.gbo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]
2019-07-03 elemental functions for R2.0 board.
    [LrE-6 Debug.cfg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]
2019-07-06 switch back to atolic
    [LrE-6-B_Cu.gbl, LrE-6-B_Mask.gbs, LrE-6-B_SilkS.gbo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]
2019-07-11 0.02
    Fully functional board revision 2.0(except wifi)
2019-08-13 LrE6 Board R2.01
    [LrE-6-B_Cu.gbl, LrE-6-B_Mask.gbs, LrE-6-B_SilkS.gbo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]
2019-08-14 0.03 final for Board R2.0
2019-08-25 final for R2.00 board
2019-08-25 R2.00 board final
2019-08-26 0.1 for board R2.01 first commit
2019-08-31 Move to MX5.3 & VID/PID => 0x1209/0xA320
2019-09-11 Back to Atollic + MX5.3 with latest modifications
    [LrE-6.kicad_pcb]
2019-09-21 0.11-pre2 fix for 9.5KQ encoder
2019-09-25 0.11-pre3 restore 'missing key relase'
    [main.c]
2019-09-26 0.11-pre4 optimize handling for encoders
2019-10-29 0.23-pre6 moved to STM32CubeIDE
2020-02-02 pb R2.1pre
    [LrE-6.kicad_pcb, LrE-6.sch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]
2020-02-24 0.28-6
    change Rotary Encoder from 9.5KQ to 'symmetry hole' model.
    [LrE-6.kicad_pcb, LrE-6.sch]
2020-03-02 0.28-7
    F2.2 PCB ordered.
    [LrE-6.kicad_pcb, LrE-6.sch]
2020-03-04 0.30
    MX Application Structure switched to 'Advanced'
2020-03-05 0.31
    Moved to STM32F0 1.11.0 based.
2020-03-15 0.32
    F2.2 PB first run
    [LrE-6.kicad_pcb, LrE-6.sch]
2020-03-16 0.32-1
    Fixed SSD1306 Horizontal paging initialize
    [LrE-6.kicad_pcb, LrE-6.sch]
2020-03-19 0.33
    enables I2C TX DMA
    [LrE-6.xls]
2020-03-24 0.33-1
    modify EC11/9.5KQ structure.
    [LrE-6.kicad_pcb]
2020-03-26 0.33-3
    remove un-needed sources for F2.2 board.
2020-03-29 0.33-4
    Add Knob FreeCAD resources
    [KNOB.FCStd, KNOBx12.FCStd, KNOBx6.FCStd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]
2020-04-04 0.33-5
    F2.8 board
    [KNOB.FCStd, KNOBx12.FCStd, KNOBx6.FCStd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]
2020-04-04 0.33-6
    add Graphical banner message.
    [KNOB.FCStd, Knobx6.stl, knob12.stl]
2020-04-05 0.34
    Add rotary encoder knob FreeCAD data
    [KNOB.FCStd, KNOB1.FCStd, KNOB12.FCStd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]
2020-04-06 0.34-1
    modify comments for doxygen
    [LrE-6.bom.xls, LrE-6.sch, LrE-6.xls]
2020-04-07 0.34-2
    C
    [LrE-6.bom.xls]
2020-04-15 0.34-5
    Delete i2c-lcd.h depend
2020-05-03 0.35-3
    fix for WS2812 LEDs
    [led.c, main.h]
2020-05-04 0.36
    temporary fix for WS2812 LEDs.
    note: 'stm32f0xx_hal_tim.c' must compile with no optimization.(-O0)
    [led.c, main.c, main.h]
2020-05-16 0.37
    LED axis settings are marged into key definition.
2020-05-23 0.37-4
    some workaround did for OLED issue.
    [main.c]
2020-06-08 0.37-6
    Fix pb for OLED stability.
    [LrE-6.bom.csv, LrE-6.bom.xls, LrE-6.bom.xlsx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]
2020-06-09 0.37-7
    LrE-6.pb F2.8-1 is ready for order.
    [LrE-6.bom.xlsx, LrE-6_F2.8-1.bom.xlsx]
2020-06-19 wiki image renaming
    [LrE-6.kicad_pcb]
2020-09-11 0.39
    Fix for HID mode
    [key_define.c, main.h]
2020-09-18 0.41-pre
    moved STM32Cube FW_F0_V1.11.1 & activate TIM7 for cancelling chatter.
2020-09-21 0.42-2
    Key definition fix.
    [key_define.c]
2020-09-25 0.42-3
    Consider EC11 encoders
2020-10-26 First commit for F3.2PB
    [LrE-6.kicad_pcb, LrE-6.sch]
2020-10-28 F3.2 add coper por inhibit
    [LrE-6.kicad_pcb]
2020-10-31 F3.2 commit for order pb
    [LrE-6.kicad_pcb]
2021-01-13 0.43
    Change initial LCD/LED initialize sequence.
2021-02-07 Rename LrE-6.pb F3.2 to F2.8-2
    [LrE-6.kicad_pcb]
2021-02-25 folk 4-layer pb as F4.0
    [LrE-6.bom.csv, LrE-6.dsn, LrE-6.kicad_pcb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]
2021-02-27 F4.0 board order
    [LrE-6.bom.csv, LrE-6.dsn, LrE-6.kicad_pcb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]
2021-02-28 0.44pre
    Prepare for F4.0 board.
2021-02-28 0.44-pre2
    moved to STM32Cube FW_F0 V1.11.2
2021-03-06 0.44-pre3
    for F4.0 board, select EC11 encoder as default.
2021-03-11 0.44
    F4.0 board relased.
2021-03-11 0.44-1
    Encoder on F4.0 board determined as 9.5KQ type.
2021-04-09 0.45
    Change rotary encoder de-bouncer capacitor value.
    [LrE-6.bom.csv, LrE-6.sch]
2021-04-09 0.45-1
    rename LrE-6.pb to LrE-6.2lpb
    [LrE-6.bom.csv, LrE-6.dsn, LrE-6.kicad_pcb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]
2021-04-17 0.45-4
    correct internal state about Scene Key,r emove dead code, correct typos.
    [main.c]
2021-06-07 0.45-6
    Fix some key defines.
    [key_define.c, led.c, led.h]
2021-06-07 0.46
    Add Error_Handler() to USB MIDI initialize.
    [main.c, main.h]
2021-06-20 0.46-1
    adjust PWM pulse width for LED. to meet LED spec.
2021-06-26 0.46-2
    (Again) adjusst PWM LED pulse width to meet WS2812C-2020 spec.
2021-07-07 0.47
    backport from LrMAX coding and
    Clean up LrE-6.2lpb old resources.
    [LrE-6.sch, LrE-6_F2.8-1.bom.xlsx]
2021-07-08 0.47-2
    fix current USB descriptor.
2021-10-22 0.49
    Back to 0.47-2 and apply 0.48(except GPIO/TIM3ch1 LEDs control).
2021-10-22 0.49-1
    Stop ADC.
2022-02-10 0.58-pre03
    compiled without errors
    [key_define.c, led.c, led.h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]
2022-02-12 0.58-pre09
    Fixed encoder axis assignment.
    [LrE-6.ioc, main.c, main.h]
2022-02-12 0.58-1
    fix connection banner
    [main.c]

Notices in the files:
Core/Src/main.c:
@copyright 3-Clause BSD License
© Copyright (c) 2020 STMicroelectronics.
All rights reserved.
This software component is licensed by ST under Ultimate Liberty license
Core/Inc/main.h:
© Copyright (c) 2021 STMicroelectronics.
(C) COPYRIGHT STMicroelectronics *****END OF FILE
